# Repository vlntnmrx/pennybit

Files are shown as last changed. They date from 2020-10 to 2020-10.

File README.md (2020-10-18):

# PennyBIT

This borad is a very stripped-down feather style bord using a Cortex-M0 by ST. The main goal was to create a board with a BOM <$2.5 to use in everyday projects while still preserving the key functions of a Adafruit(R) Feather, like the LiPo Charger and the pinout. As a bonus, three of the pins are driven by MOSFETs e.g. to allow the use of RBG LED strips.

## Tech Spec
* STM32F042K6T Microcontroller
* MCP73831 LiPo Charger
* Built in USB-bootloader
* Access to SWD port
* Boot button, usable as user input in normal operation
* Pin compatible to Adafruit(R) Feather

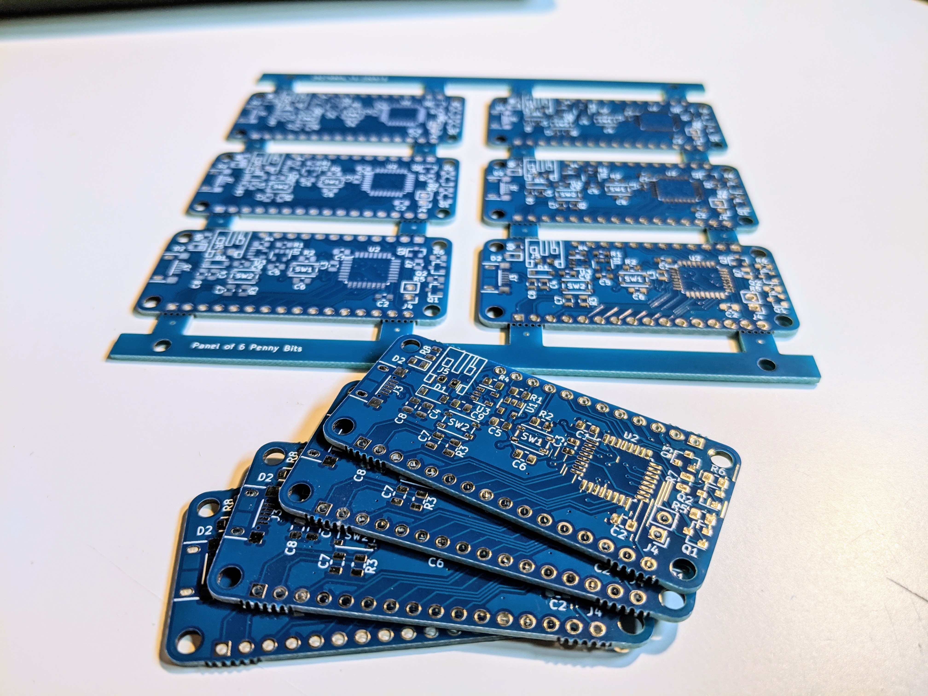
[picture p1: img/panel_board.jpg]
First revision production


## Current state
First batch is assembled and tested. No Problems found (yet) :smile:

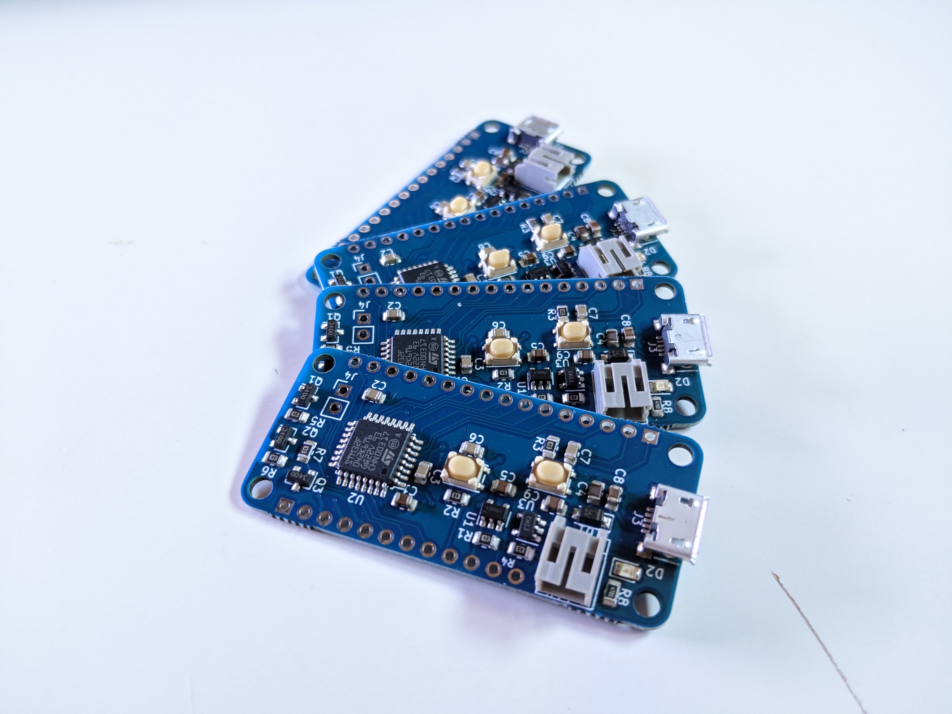
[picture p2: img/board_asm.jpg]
Assembled Boards


### Note
The project was originally called "cheapFeather" so some files still carry this name.

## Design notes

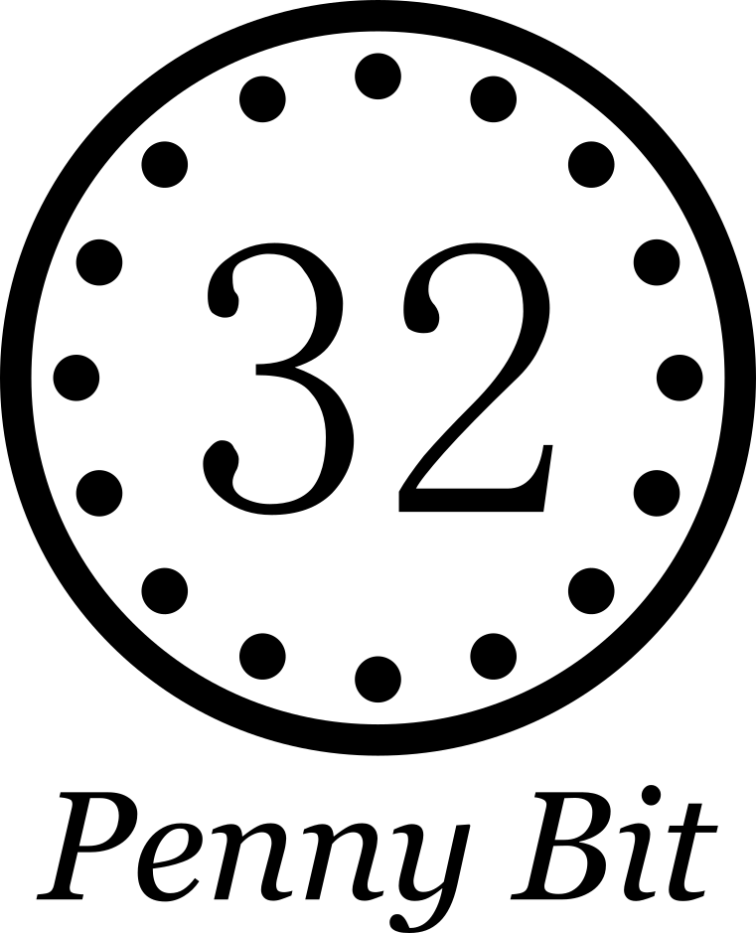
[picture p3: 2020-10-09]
coin.png

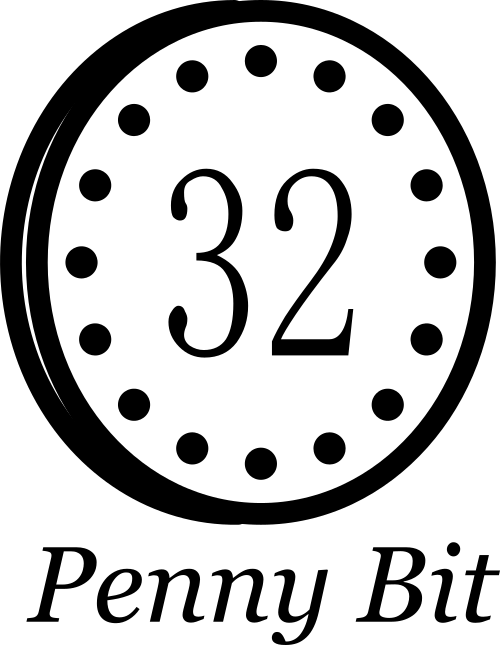
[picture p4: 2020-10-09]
coin_angle.png

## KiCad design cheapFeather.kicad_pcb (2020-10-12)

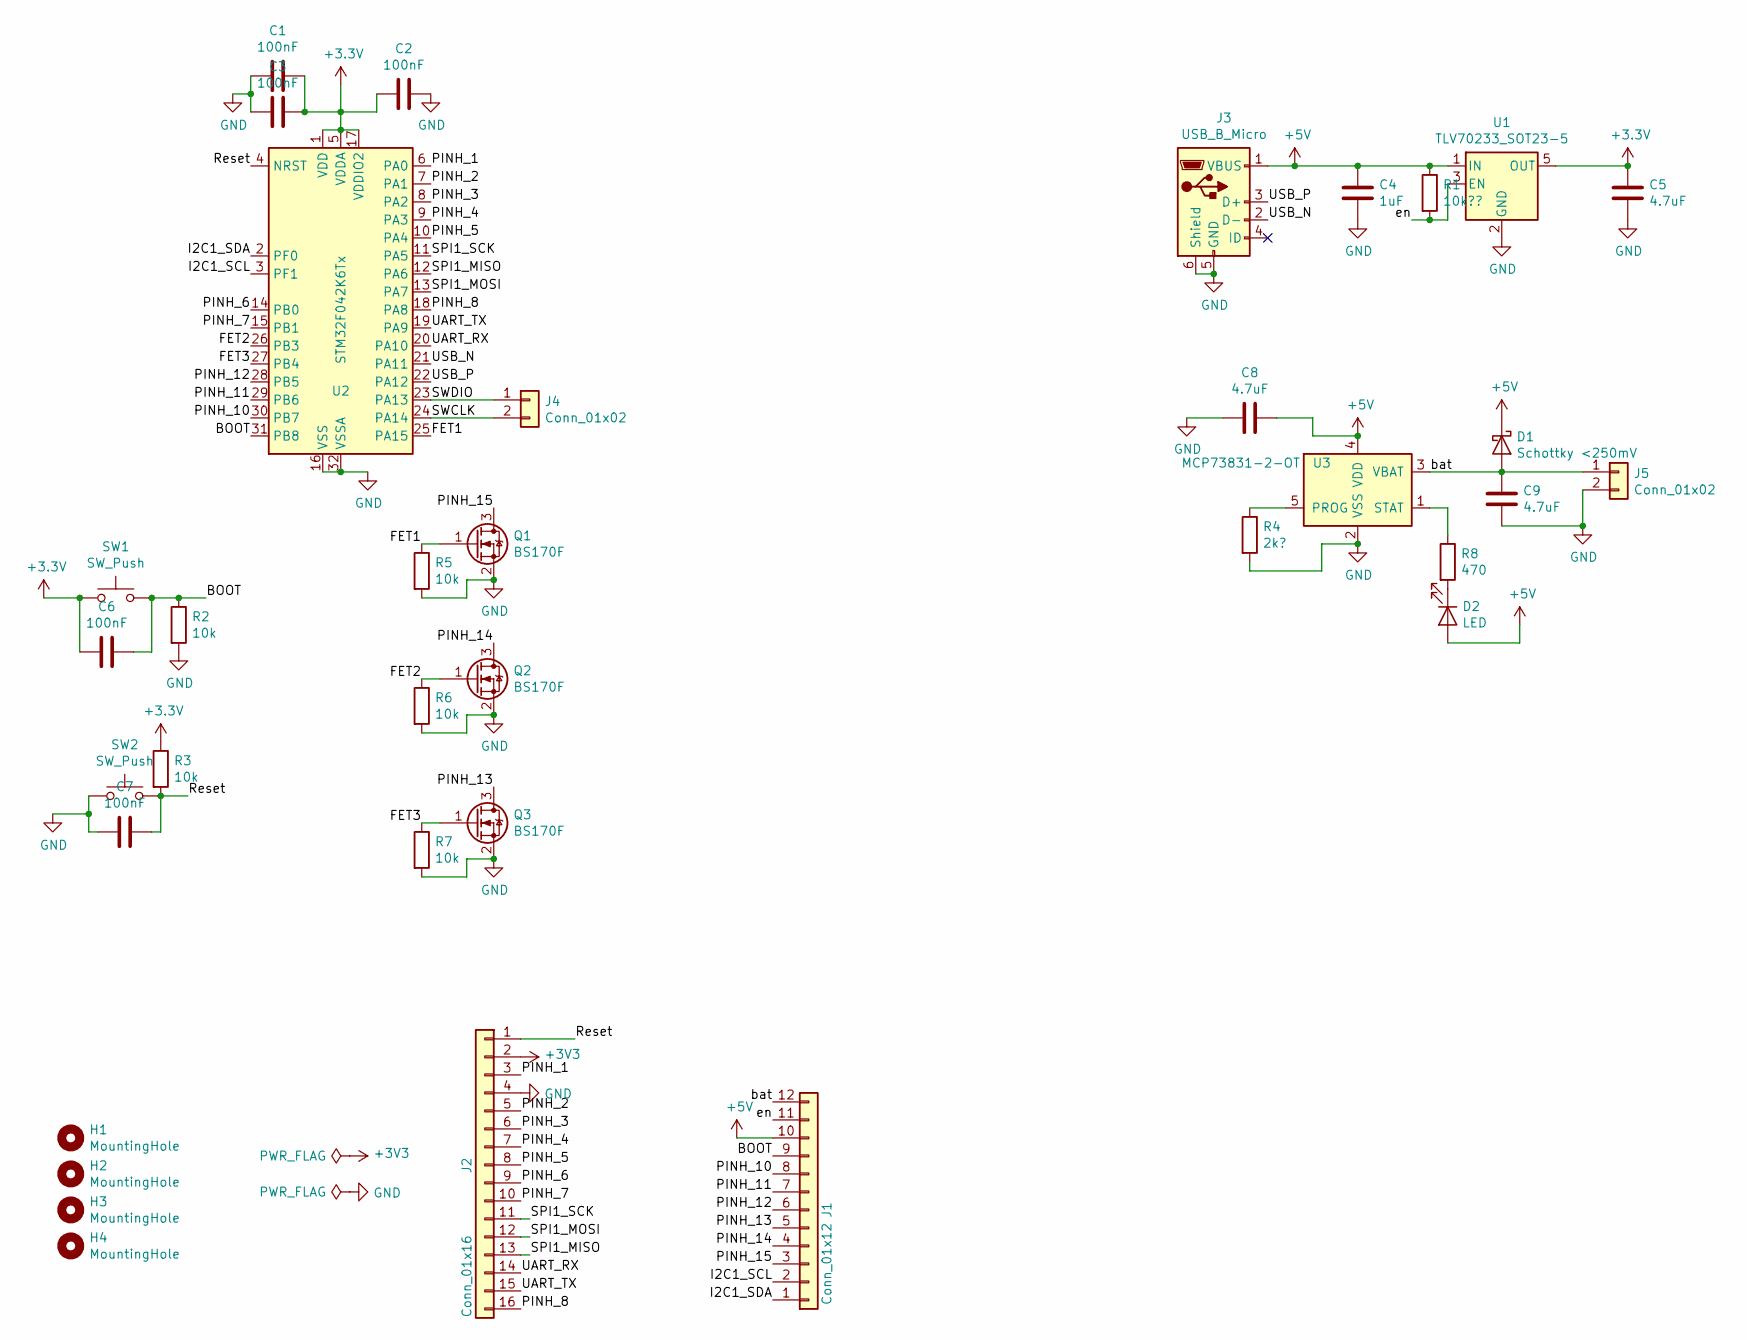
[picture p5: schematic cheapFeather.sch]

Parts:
C1, C2, C3, C6, C7: 100nF; C_0805_2012Metric
C4: 1uF; C_0805_2012Metric
C5, C8, C9: 4.7uF; C_0805_2012Metric
D1: Schottky <250mV; D_SOD-123
D2: LED; LED_0805_2012Metric
H1, H2, H3, H4: MountingHole; MountingHole_2.7mm_M2.5
J1: Conn_01x12; PinHeader_1x12_P2.54mm_Vertical
J2: Conn_01x16; PinHeader_1x16_P2.54mm_Vertical
J3: USB_B_Micro; USB_Micro_XKB
J4: Conn_01x02; PinHeader_1x02_P2.54mm_Vertical
J5: Conn_01x02; JST_PH_S2B-PH-K_1x02_P2.00mm_Horizontal
Q1, Q2, Q3: BS170F; SOT-23
R1: 10k??; R_0805_2012Metric
R2, R3, R5, R6, R7: 10k; R_0805_2012Metric
R4: 2k?; R_0805_2012Metric
R8: 470; R_0805_2012Metric
SW1, SW2: SW_Push; SW_SPST_PTS810
U1: TLV70233_SOT23-5; SOT-23-5
U2: STM32F042K6Tx; LQFP-32_7x7mm_P0.8mm
U3: MCP73831-2-OT; SOT-23-5

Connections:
+5V: C4.1, C8.1, D1.1 (K), D2.2 (A), J1.10, J3.1 (VBUS), R1.1, U1.1 (IN), U3.4 (VDD)
/BOOT: C6.1, J1.9, R2.1, SW1.2, U2.31 (PB8)
/FET1: Q1.1 (G), R5.1, U2.25 (PA15)
/FET2: Q2.1 (G), R6.1, U2.26 (PB3)
/FET3: Q3.1 (G), R7.1, U2.27 (PB4)
/I2C1_SCL: J1.2, U2.3 (PF1)
/I2C1_SDA: J1.1, U2.2 (PF0)
/PINH_1: J2.3, U2.6 (PA0)
/PINH_2: J2.5, U2.7 (PA1)
/PINH_3: J2.6, U2.8 (PA2)
/PINH_4: J2.7, U2.9 (PA3)
/PINH_5: J2.8, U2.10 (PA4)
/PINH_6: J2.9, U2.14 (PB0)
/PINH_7: J2.10, U2.15 (PB1)
/PINH_8: J2.16, U2.18 (PA8)
/PINH_10: J1.8, U2.30 (PB7)
/PINH_11: J1.7, U2.29 (PB6)
/PINH_12: J1.6, U2.28 (PB5)
/PINH_13: J1.5, Q3.3 (D)
/PINH_14: J1.4, Q2.3 (D)
/PINH_15: J1.3, Q1.3 (D)
/Reset: C7.1, J2.1, R3.2, SW2.2, U2.4 (NRST)
/SPI1_MISO: J2.13, U2.12 (PA6)
/SPI1_MOSI: J2.12, U2.13 (PA7)
/SPI1_SCK: J2.11, U2.11 (PA5)
/SWCLK: J4.2, U2.24 (PA14)
/SWDIO: J4.1, U2.23 (PA13)
/UART_RX: J2.14, U2.20 (PA10)
/UART_TX: J2.15, U2.19 (PA9)
/USB_N: J3.2 (D-), U2.21 (PA11)
/USB_P: J3.3 (D+), U2.22 (PA12)
/bat: C9.1, D1.2 (A), J1.12, J5.1, U3.3 (VBAT)
/en: J1.11, R1.2, U1.3 (EN)
GND: C1.2, C2.1, C3.2, C4.2, C5.2, C7.2, C8.2, C9.2, J2.4, J3.5 (GND), J3.6 (Shield), J5.2, Q1.2 (S), Q2.2 (S), Q3.2 (S), R2.2, R4.2, R5.2, R6.2, R7.2, SW2.1, U1.2 (GND), U2.16 (VSS), U2.32 (VSSA), U3.2 (VSS)
unnamed: D2.1 (K), R8.2
unnamed: R4.1, U3.5 (PROG)
unnamed: R8.1, U3.1 (STAT)

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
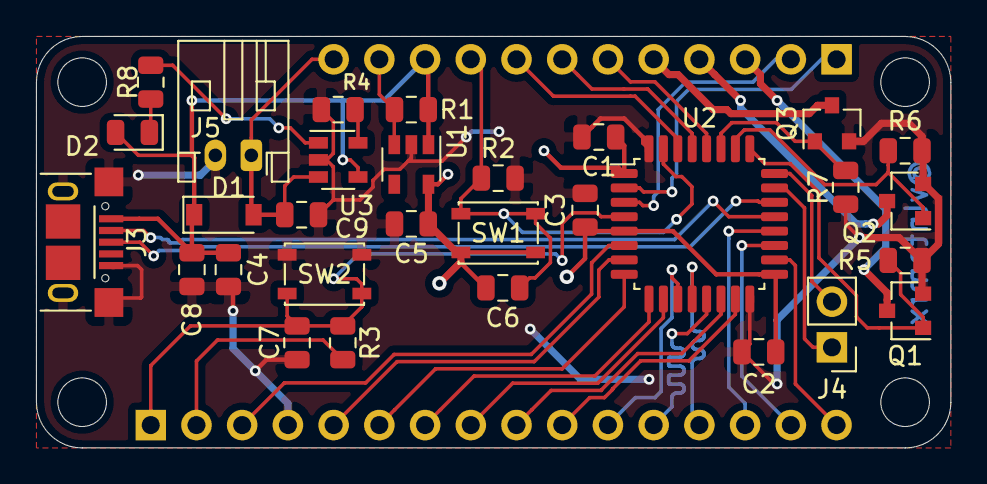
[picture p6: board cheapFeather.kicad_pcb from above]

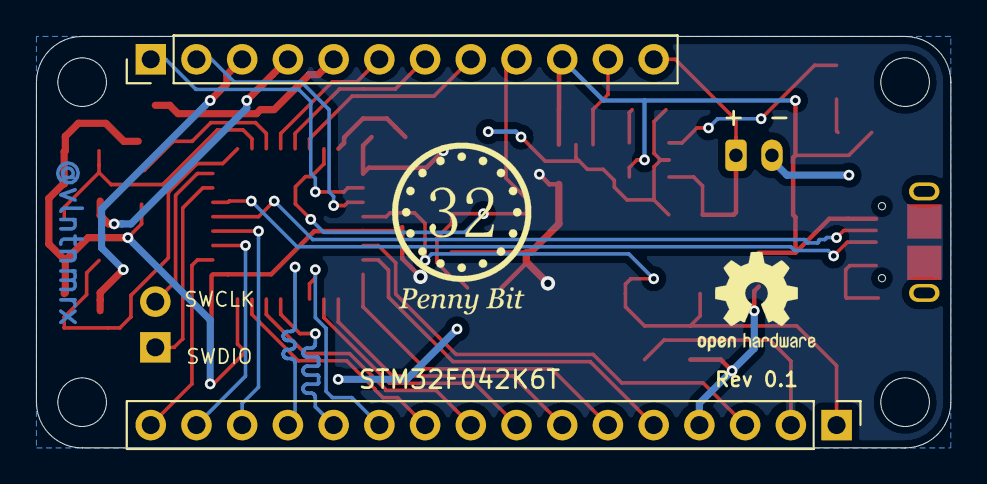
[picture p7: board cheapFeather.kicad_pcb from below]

Board: 2 copper layers, 50.8 x 22.9 mm, 36 parts (2 on the bottom side), 38 nets.

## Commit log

2020-10-09 Init Commit
    [cheapFeather-B_Cu.gbr, cheapFeather-B_Mask.gbr, cheapFeather-B_Paste.gbr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]
2020-10-12 Changed cap. values
    [cheapFeather.kicad_pcb, cheapFeather.sch]
